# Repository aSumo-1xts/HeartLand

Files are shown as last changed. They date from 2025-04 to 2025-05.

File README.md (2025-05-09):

# HeartLand







Ableton LiveでDJをするためのUSB-MIDIコントローラ。

Learn more: https://blog.1xtelescope.com/posts/HeartLand.html

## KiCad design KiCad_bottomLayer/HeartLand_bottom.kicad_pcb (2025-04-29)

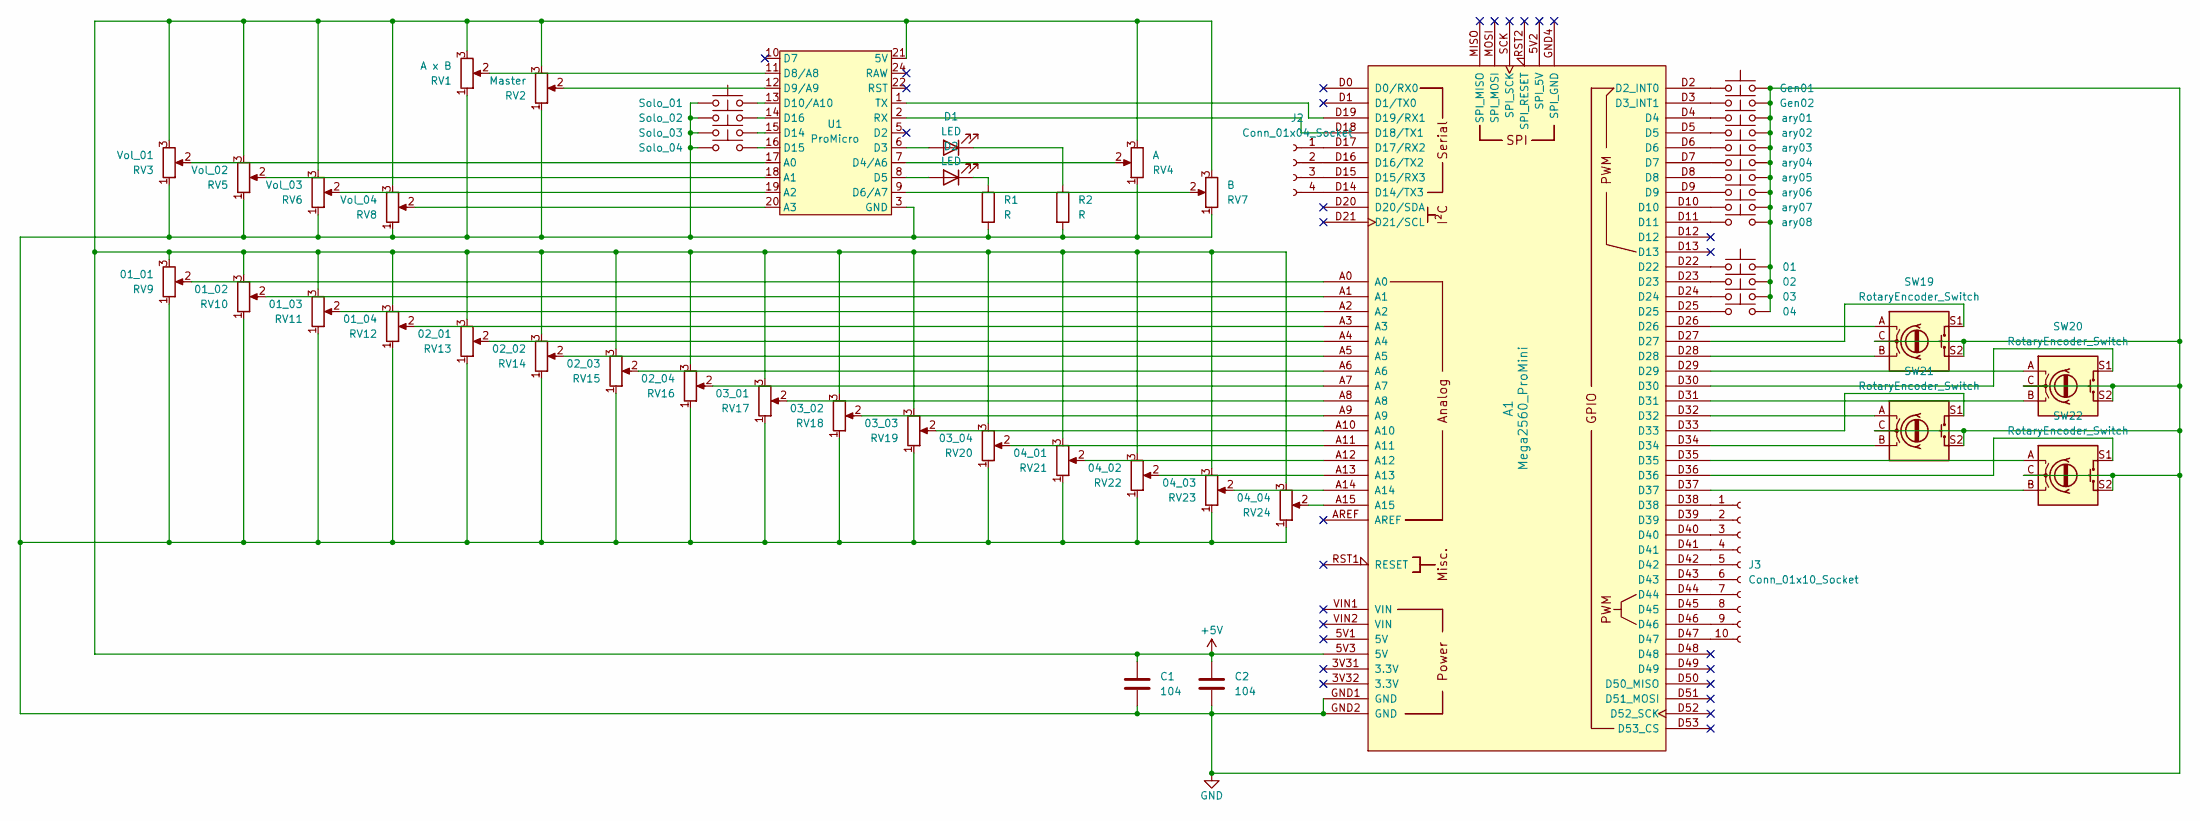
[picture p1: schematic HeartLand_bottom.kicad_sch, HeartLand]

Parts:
A1: Mega2560_ProMini; Clone_Mega2560_Pro_Socket
C1, C2: 104; C_Disc_D3.0mm_W1.6mm_P2.50mm
D1, D2: LED; LED_D10.0mm
J2: Conn_01x04_Socket; PinSocket_2x02_P2.00mm_Horizontal
J3: Conn_01x10_Socket; PinSocket_2x05_P2.54mm_Horizontal
R1, R2: R; R_Axial_DIN0204_L3.6mm_D1.6mm_P5.08mm_Horizontal
RV1: A x B; Potentiometer_Bourns_PTA4543_Single_Slide
RV2: Master; Potentiometer_Bourns_PTA4543_Single_Slide
RV3: Vol_01; Potentiometer_Bourns_PTA4543_Single_Slide
RV4: A; Potentiometer_Alps_RK09K_Single_Vertical
RV5: Vol_02; Potentiometer_Bourns_PTA4543_Single_Slide
RV6: Vol_03; Potentiometer_Bourns_PTA4543_Single_Slide
RV7: B; Potentiometer_Alps_RK09K_Single_Vertical
RV8: Vol_04; Potentiometer_Bourns_PTA4543_Single_Slide
RV9: 01_01; Potentiometer_Alps_RK09K_Single_Vertical
RV10: 01_02; Potentiometer_Alps_RK09K_Single_Vertical
RV11: 01_03; Potentiometer_Alps_RK09K_Single_Vertical
RV12: 01_04; Potentiometer_Alps_RK09K_Single_Vertical
RV13: 02_01; Potentiometer_Alps_RK09K_Single_Vertical
RV14: 02_02; Potentiometer_Alps_RK09K_Single_Vertical
RV15: 02_03; Potentiometer_Alps_RK09K_Single_Vertical
RV16: 02_04; Potentiometer_Alps_RK09K_Single_Vertical
RV17: 03_01; Potentiometer_Alps_RK09K_Single_Vertical
RV18: 03_02; Potentiometer_Alps_RK09K_Single_Vertical
RV19: 03_03; Potentiometer_Alps_RK09K_Single_Vertical
RV20: 03_04; Potentiometer_Alps_RK09K_Single_Vertical
RV21: 04_01; Potentiometer_Alps_RK09K_Single_Vertical
RV22: 04_02; Potentiometer_Alps_RK09K_Single_Vertical
RV23: 04_03; Potentiometer_Alps_RK09K_Single_Vertical
RV24: 04_04; Potentiometer_Alps_RK09K_Single_Vertical
SW1: Gen01; SW_Cherry_MX_1.00u_PCB
SW2: Solo_01; SW_Cherry_MX_1.00u_PCB
SW3: Gen02; SW_Cherry_MX_1.00u_PCB
SW4: Solo_02; SW_Cherry_MX_1.00u_PCB
SW5: ary01; SW_Cherry_MX_1.00u_PCB
SW6: Solo_03; SW_Cherry_MX_1.00u_PCB
SW7: ary02; SW_Cherry_MX_1.00u_PCB
SW8: Solo_04; SW_Cherry_MX_1.00u_PCB
SW9: ary03; SW_Cherry_MX_1.00u_PCB
SW10: ary04; SW_Cherry_MX_1.00u_PCB
SW11: ary05; SW_Cherry_MX_1.00u_PCB
SW12: ary06; SW_Cherry_MX_1.00u_PCB
SW13: ary07; SW_Cherry_MX_1.00u_PCB
SW14: ary08; SW_Cherry_MX_1.00u_PCB
SW15: 01; SW_Cherry_MX_1.00u_PCB
SW16: 02; SW_Cherry_MX_1.00u_PCB
SW17: 03; SW_Cherry_MX_1.00u_PCB
SW18: 04; SW_Cherry_MX_1.00u_PCB
SW19, SW20, SW21, SW22: RotaryEncoder_Switch; RotaryEncoder_Alps_EC12E-Switch_Vertical_H20mm
U1: ProMicro; Sparkfun_Pro_Micro

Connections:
+5V: A1.5V3 (5V), C1.1, C2.1, RV1.3, RV2.3, RV3.3, RV4.3, RV5.3, RV6.3, RV7.3, RV8.3, RV9.3, RV10.3, RV11.3, RV12.3, RV13.3, RV14.3, RV15.3, RV16.3, RV17.3, RV18.3, RV19.3, RV20.3, RV21.3, RV22.3, RV23.3, RV24.3, U1.21 (5V)
GND: A1.GND1 (GND), A1.GND2 (GND), C1.2, C2.2, R1.2, R2.2, RV1.1, RV1.MP, RV2.1, RV2.MP, RV3.1, RV3.MP, RV4.1, RV4.MP, RV5.1, RV5.MP, RV6.1, RV6.MP, RV7.1, RV7.MP, RV8.1, RV8.MP, RV9.1, RV9.MP, RV10.1, RV10.MP, RV11.1, RV11.MP, RV12.1, RV12.MP, RV13.1, RV13.MP, RV14.1, RV14.MP, RV15.1, RV15.MP, RV16.1, RV16.MP, RV17.1, RV17.MP, RV18.1, RV18.MP, RV19.1, RV19.MP, RV20.1, RV20.MP, RV21.1, RV21.MP, RV22.1, RV22.MP, RV23.1, RV23.MP, RV24.1, RV24.MP, SW1.2, SW2.1, SW3.2, SW4.1, SW5.1, SW6.1, SW7.1, SW8.1, SW9.1, SW10.1, SW11.1, SW12.1, SW13.1, SW14.1, SW15.1, SW16.1, SW17.1, SW18.1, SW19.C, SW19.MP, SW19.S2, SW20.C, SW20.MP, SW20.S2, SW21.C, SW21.MP, SW21.S2, SW22.C, SW22.MP, SW22.S2, U1.3 (GND), U1.4 (GND), U1.23 (GND)
unnamed: A1.D2 (D2_INT0), SW1.1
unnamed: A1.D3 (D3_INT1), SW3.1
unnamed: A1.D14 (D14/TX3), J2.4
unnamed: A1.D15 (D15/RX3), J2.3
unnamed: A1.D16 (D16/TX2), J2.2
unnamed: A1.D17 (D17/RX2), J2.1
unnamed: A1.D18 (D18/TX1), U1.2 (RX)
unnamed: A1.D19 (D19/RX1), U1.1 (TX)
unnamed: A1.A0, RV9.2
unnamed: A1.A1, RV10.2
unnamed: A1.A2, RV11.2
unnamed: A1.A3, RV12.2
unnamed: A1.A4, RV13.2
unnamed: A1.A5, RV14.2
unnamed: A1.A6, RV15.2
unnamed: A1.A7, RV16.2
unnamed: A1.A8, RV17.2
unnamed: A1.A9, RV18.2
unnamed: A1.A10, RV19.2
unnamed: A1.A11, RV20.2
unnamed: A1.A12, RV21.2
unnamed: A1.A13, RV22.2
unnamed: A1.A14, RV23.2
unnamed: A1.A15, RV24.2
unnamed: A1.D4, SW5.2
unnamed: A1.D5, SW7.2
unnamed: A1.D6, SW9.2
unnamed: A1.D7, SW10.2
unnamed: A1.D8, SW11.2
unnamed: A1.D9, SW12.2
unnamed: A1.D10, SW13.2
unnamed: A1.D11, SW14.2
unnamed: A1.D22, SW15.2
unnamed: A1.D23, SW16.2
unnamed: A1.D24, SW17.2
unnamed: A1.D25, SW18.2
unnamed: A1.D26, SW19.A
unnamed: A1.D27, SW19.S1
unnamed: A1.D28, SW19.B
unnamed: A1.D29, SW20.A
unnamed: A1.D30, SW20.S1
unnamed: A1.D31, SW20.B
unnamed: A1.D32, SW21.A
unnamed: A1.D33, SW21.S1
unnamed: A1.D34, SW21.B
unnamed: A1.D35, SW22.A
unnamed: A1.D36, SW22.S1
unnamed: A1.D37, SW22.B
unnamed: D1.2 (A), U1.6 (D3)
unnamed: D1.1 (K), R2.1
unnamed: D2.2 (A), U1.8 (D5)
unnamed: D2.1 (K), R1.1
unnamed: A1.D38, J3.1
unnamed: A1.D39, J3.2
unnamed: A1.D40, J3.3
unnamed: A1.D41, J3.4
unnamed: A1.D42, J3.5
unnamed: A1.D43, J3.6
unnamed: A1.D44, J3.7
unnamed: A1.D45, J3.8
unnamed: A1.D46, J3.9
unnamed: A1.D47, J3.10
unnamed: RV3.2, U1.17 (A0)
unnamed: RV5.2, U1.18 (A1)
unnamed: RV6.2, U1.19 (A2)
unnamed: RV8.2, U1.20 (A3)
unnamed: RV4.2, U1.7 (D4/A6)
unnamed: RV7.2, U1.9 (D6/A7)
unnamed: RV1.2, U1.11 (D8/A8)
unnamed: RV2.2, U1.12 (D9/A9)
unnamed: SW2.2, U1.13 (D10/A10)
unnamed: SW6.2, U1.15 (D14)
unnamed: SW8.2, U1.16 (D15)
unnamed: SW4.2, U1.14 (D16)

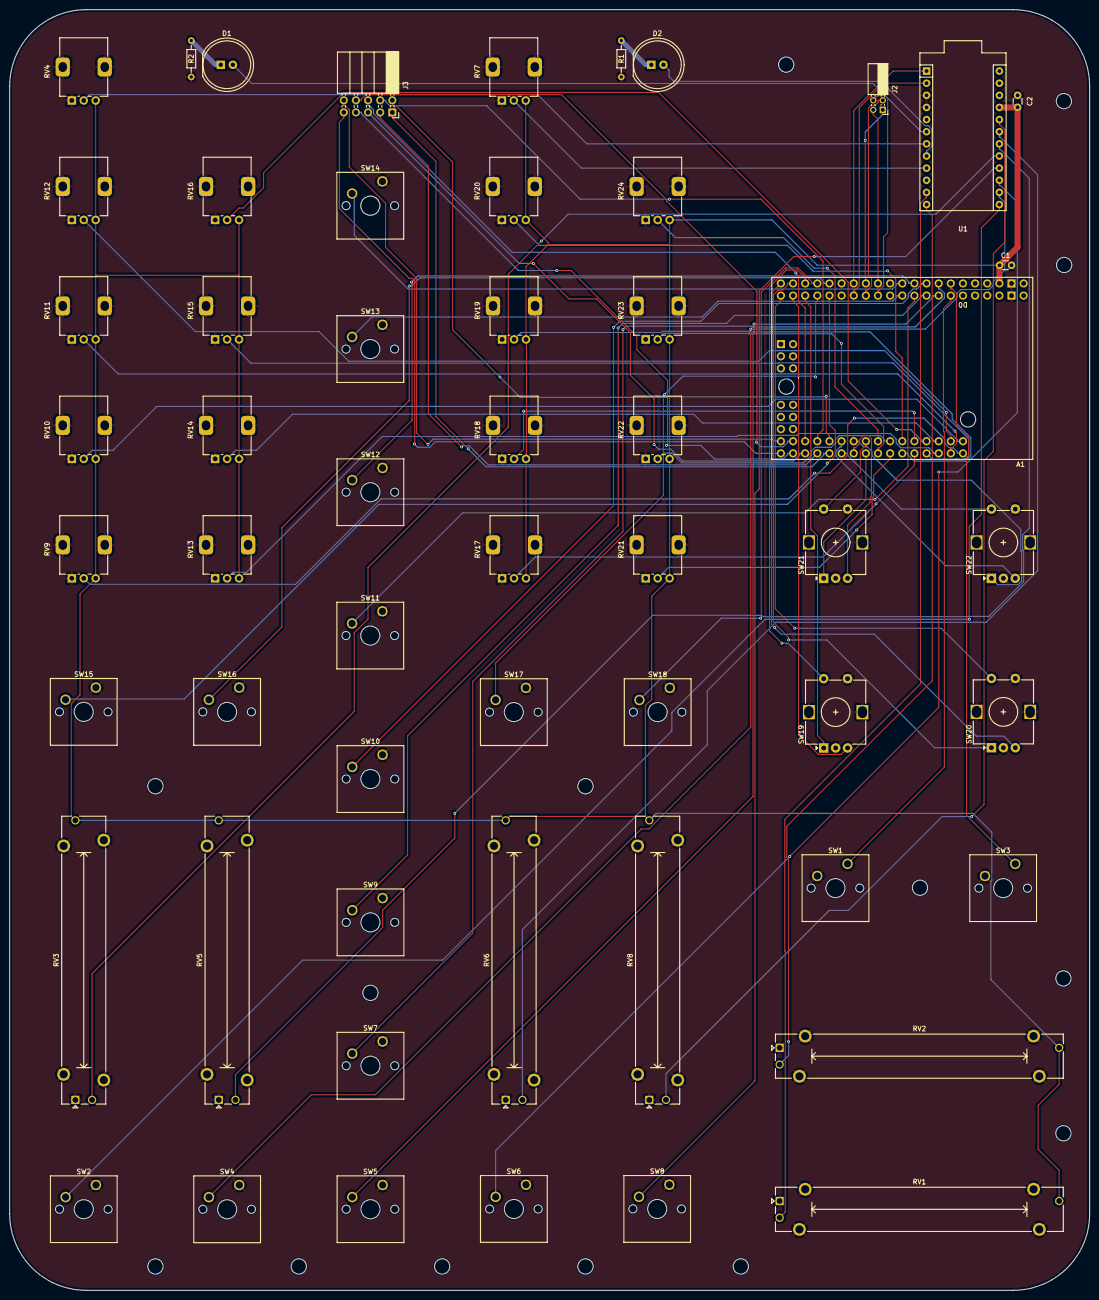
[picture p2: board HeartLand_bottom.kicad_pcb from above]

Board: 2 copper layers, 226.0 x 268.0 mm, 70 parts (0 on the bottom side), 76 nets.

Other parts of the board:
M3, M3#2, M3#3, M3#4, M3#5, M3#6, M3#7, M3#8, M3#9, M3#10, M3#11, M3#12, M3#13, M3#14: MountingHole_3.2mm_M3

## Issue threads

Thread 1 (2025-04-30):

PlatformIO環境に移行しようとする際のエラー

aSumo-1xts, 2025-04-30:
# PlatformIO環境に移行しようとする際のエラー

当方で確認済みの事項は以下です。

## `mother.ino`

### 関数のプロトタイプ宣言

本プロジェクトでは`.ino`ファイル特有の暗黙的な自動プロトタイプ宣言を利用しています。

PlatformIO移行時に`.cpp`に直す場合には、`setup()`関数および`loop()`関数を最後に置くか、あるいは`realTimeMessageCallback()`関数を先頭で明示的にプロトタイプ宣言する必要があります。

## `daughter.ino`

### MIDIUSBライブラリを利用できない旨のエラー

> #error MIDIUSB can only be used with an USB MCU.

前提として、`daughter.ino`を書き込む対象がArduino Mega Pro MiniなどUSBインターフェースにCH340を使ったものである場合、MIDIUSBライブラリを用いることはできません。

従って`daughter.ino`ではMIDIUSBライブラリの機能を使っていませんが、Control-Surfaceライブラリ中でMIDIUSBライブラリが形式的に呼び出され、これがPlatformIOもといAVRDUDEではエラーを引き起こすようです。

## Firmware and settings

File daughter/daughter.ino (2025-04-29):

/**
 * @file        heartLand_daughter.ino
 * @author      aSumo (1xtelescope@gmail.com)
 * @brief       a sketch for Mega2560 ProMini in USB-MIDI Controller "HeartLand"
 * @version     1.0
 * @date        2024-06-26
 * @copyright   GPL-3.0
 * @details     Just send serial MIDI message from Serial1 to "mother"
 */

//! https://github.com/tttapa/Control-Surface.git
#include <Control_Surface.h>
//! 単純なシリアル通信のためのインスタンス
SerialMIDI_Interface<decltype(Serial1)> midi_ser{Serial1, MIDI_BAUD};

/* ↓↓↓↓↓↓↓↓↓↓↓↓↓↓↓ variable to change ↓↓↓↓↓↓↓↓↓↓↓↓↓↓↓ */

uint8_t ch[3] = {2, 3, 4};  //!< MIDIチャンネルの管理
uint8_t BPM_multi = 5;      //!< BPM用エンコーダの係数
uint8_t enc_multi = 5;      //!< 汎用エンコーダの係数

/* ↑↑↑↑↑↑↑↑↑↑↑↑↑↑↑ variable to change ↑↑↑↑↑↑↑↑↑↑↑↑↑↑↑ */

uint8_t util01 = 2;  //!< 余りその1
uint8_t util02 = 3;  //!< 余りその2

CCAbsoluteEncoder enc[] = {
    {
        {26, 28},
        {3, Channel::createChannel(ch[0])},
        BPM_multi,
    },  // enc01
    {
        {29, 31},
        {4, Channel::createChannel(ch[0])},
        enc_multi,
    },  // enc02
    {
        {32, 34},
        {5, Channel::createChannel(ch[0])},
        enc_multi,
    },  // enc03
    {
        {35, 37},
        {6, Channel::createChannel(ch[0])},
        enc_multi,
    },  // enc04
};

CCButton sw[] = {
    {
        27,
        {7, Channel::createChannel(ch[0])},
    },  // enc_sw01
    {
        30,
        {8, Channel::createChannel(ch[0])},
    },  // enc_sw02
    {
        33,
        {9, Channel::createChannel(ch[0])},
    },  // enc_sw03
    {
        36,
        {10, Channel::createChannel(ch[0])},
    },  // enc_sw04

    {
        4,
        {11, Channel::createChannel(ch[0])},
    },  // ary01
    {
        5,
        {12, Channel::createChannel(ch[0])},
    },  // ary02
    {
        6,
        {13, Channel::createChannel(ch[0])},
    },  // ary03
    {
        7,
        {14, Channel::createChannel(ch[0])},
    },  // ary04
    {
        8,
        {15, Channel::createChannel(ch[0])},
    },  // ary05
    {
        9,
        {16, Channel::createChannel(ch[0])},
    },  // ary06
    {
        10,
        {17, Channel::createChannel(ch[0])},
    },  // ary07
    {
        11,
        {18, Channel::createChannel(ch[0])},
    },  // ary08

    {
        22,
        {6, Channel::createChannel(ch[1])},
    },  // Sw01
    {
        23,
        {7, Channel::createChannel(ch[1])},
    },  // Sw02

    {
        24,
        {6, Channel::createChannel(ch[2])},
    },  // Sw03
    {
        25,
        {7, Channel::createChannel(ch[2])},
    },  // Sw04
};

CCPotentiometer pot[] = {
    {
        A0,
        {8, Channel::createChannel(ch[1])},
    },  // pot01_01
    {
        A1,
        {9, Channel::createChannel(ch[1])},
    },  // pot01_02
    {
        A2,
        {10, Channel::createChannel(ch[1])},
    },  // pot01_03
    {
        A3,
        {11, Channel::createChannel(ch[1])},
    },  // pot01_04
    {
        A4,
        {12, Channel::createChannel(ch[1])},
    },  // pot02_01
    {
        A5,
        {13, Channel::createChannel(ch[1])},
    },  // pot02_02
    {
        A6,
        {14, Channel::createChannel(ch[1])},
    },  // pot02_03
    {
        A7,
        {15, Channel::createChannel(ch[1])},
    },  // pot02_04

    {
        A8,
        {8, Channel::createChannel(ch[2])},
    },  // pot03_01
    {
        A9,
        {9, Channel::createChannel(ch[2])},
    },  // pot03_02
    {
        A10,
        {10, Channel::createChannel(ch[2])},
    },  // pot03_03
    {
        A11,
        {11, Channel::createChannel(ch[2])},
    },  // pot03_04
    {
        A12,
        {12, Channel::createChannel(ch[2])},
    },  // pot04_01
    {
        A13,
        {13, Channel::createChannel(ch[2])},
    },  // pot04_02
    {
        A14,
        {14, Channel::createChannel(ch[2])},
    },  // pot04_03
    {
        A15,
        {15, Channel::createChannel(ch[2])},
    },  // pot04_04
};

//! @brief setup関数
void setup() {
  pinMode(util01, INPUT_PULLUP);
  pinMode(util02, INPUT_PULLUP);

  Control_Surface.begin();
}

//! @brief loop関数
void loop() { Control_Surface.loop(); }

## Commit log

2025-04-22 update: README.mdを編集
2025-04-29 add: KiCadファイル3種を追加
    [HeartLand_bottom.kicad_pcb, HeartLand_bottom.kicad_sch, HeartLand_top.kicad_pcb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]
2025-04-29 add: Arduinoスケッチを追加
2025-05-09 update: READMEのバッジを編集
2025-05-09 add: arduino-cliを導入

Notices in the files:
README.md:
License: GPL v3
